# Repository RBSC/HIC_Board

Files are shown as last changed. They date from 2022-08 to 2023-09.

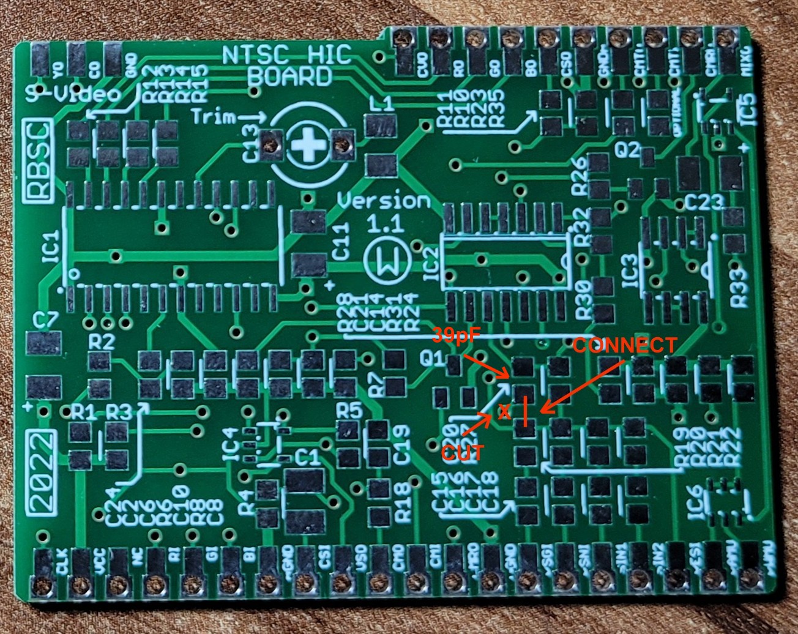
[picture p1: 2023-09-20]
Pics/v1_board_fix.jpg

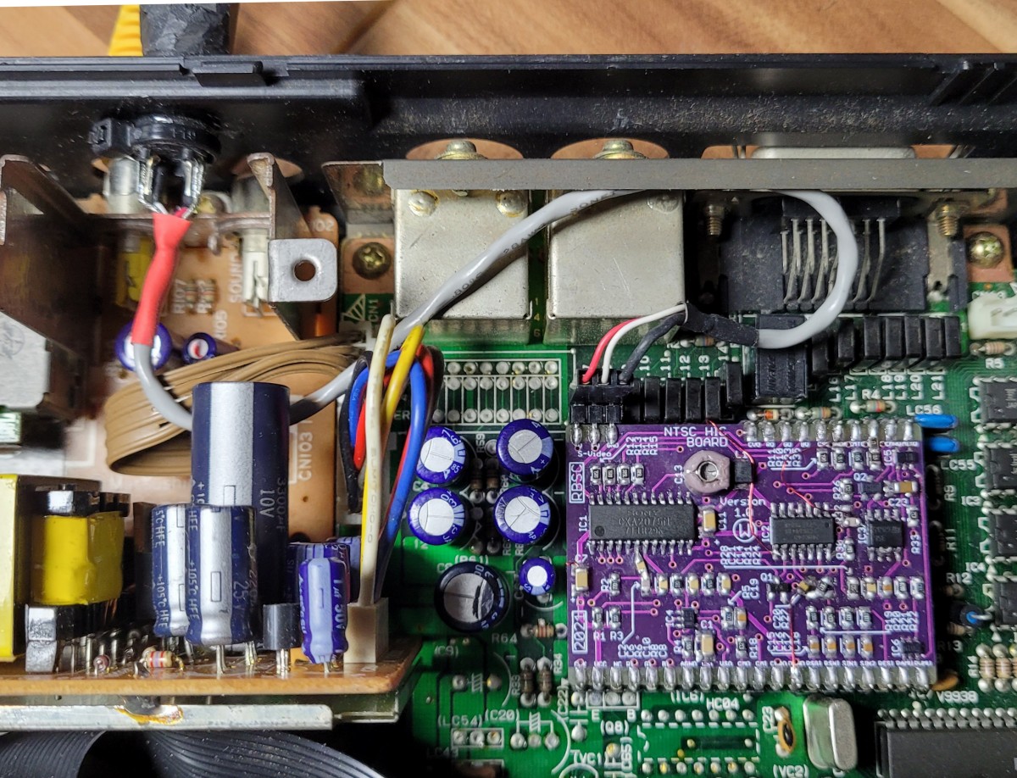
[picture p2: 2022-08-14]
Pics/installed.jpg

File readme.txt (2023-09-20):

--------------------------------------------------------------------------------
HIC Board version 1.2
Copyright (c) 2021-2023 RBSC
Last updated: 21.09.2023
--------------------------------------------------------------------------------

About
-----

It's a well-known fact that certain MSX2/2+ computers have a so-called "HIC Board" - the special "Hybrid IC" daughterboard that is
mounted onto the MSX computer's motherboard and provides certain functionality. This functionality is as follows:

 - converts RGBS signals to composite video
 - pre-amplifies and buffers audio
 - mutes audio at startup and on pause to prevent clicks
 - mixes all audio inputs
 - amplifies and buffers the cassette interface signals
 - buffers cassette interface's relay operations

This board is known to be installed in the following MSX computers:

 - Sony HB-F1II
 - Sony HB-F1XD
 - Sony HB-F1XV
 - Sony HB-F1XDJ
 - Sony HB-F1XDmkII
 - Panasonic FS-A1mkII
 - Panasonic FS-A1F
 - Kawai KMC-5000 (Panasonic FS-A1F OEM)

Normally, the board works just fine, but there's a problem with 3 electrolytic capacitors - they leak and damage the board,
sometimes beyond repair. Fixing the leaked boards is difficult as some components can separate from the corroded solder pads,
some tracks can be corroded under the CXA chip resulting in the board's malfunction.

The original HIC board's schematics and layout can be found here:
http://elec-junker-p2.blog.jp/MITSUMI%20EMC-NX0039_REV02_PU.pdf

HIC Board's Redesign
--------------------

Taking into account all the above listed problems, it was decided to clone the HIC board and at the same time add the following
improvements:

 - use a better and commonly available encoder chip CXA2075
 - add s-video output capability
 - try to get rid of the original 4069UBF chip's dependency
 - make the HIC board detachable

It was also desired to get rid of the 2 special components: IMN10 and FMW1, but they appeared to be still available for purchasing,
so they remained on the redesigned board.

During the redesign there appeared a few problems. The 4069UBF chip from Toshiba was used by the original engineers as an amplifier,
so the board's audio and cassette interface operations were dependent on certain features of that chip. When trying to replace this
chip with similar ones, for example 74LS04 or 74HCT04, the audio functionality was crippled. The only possible replacement appears
to be 74HC04 with 68pF capacitor added between pins 3 and 7 (GND). See the "74hc04_fix.jpg" image in the Pics folder.

The optional resistor R35 should not be installed unless the cassette input circuit doesn't work as desired.

Please note that R39 should be 0 Ohm resistor for all computers except for HB-F1XDJ. On that particular computer R39 should
be 220k.

Where to buy parts
------------------

At the time of this readme's creation the parts are available from the following sellers:

 - pin headers (male and female): https://www.aliexpress.com/item/4001122376295.html
 - CXA2075 encoder: https://www.aliexpress.com/item/33020885081.html
 - 4069UBF: https://www.aliexpress.com/item/1005002494421415.html
 - 68uH inductor: https://www.aliexpress.com/item/1005002963165525.html
 - LMV358M amplifier: https://www.aliexpress.com/item/4001116443945.html
 - 68pF trim capacitor: https://www.aliexpress.com/item/4000222152928.html
 - 2SA1037 transistor: https://www.aliexpress.com/item/1005002503421569.html
 - 2SC2411 transistor: https://www.aliexpress.com/item/1005004568437670.html
 - IMN10: https://www.aliexpress.com/item/1005004322498640.html
 - FMW1: https://www.ebay.com/itm/325038640119 or from Wierzbowsky (RBSC)

The resistors and capacitors 0805 and 1210 form factor can be ordered from any reasonable seller. The boards can be ordered from the
JLCPCB.COM factory.

IMPORTANT!
----------

The board hasn't been tested on all available MSX2/MSX2+ computers that are listed above. So far, the board was proved to be working
well on Panasonic A1 series computers, as well as on Sony F1-XV. There's still no feedback from some people who bought the HIC board
kits for other computers. As a result, the project's status is still WIP (work in progress).

The boards version 1.0 and 1.1 have an error that results in problems with PSG and FM sound on Sony HB-F1XDJ. The information on how
to fix the problem with those boards can be found in the "v1_board_fix.jpg" image file. One trace needs to be cut, 2 pads need to be
connected and C20 needs to be replaced with 39pF capacitor.

The RBSC provides all the files and information for free, without any liability (see the disclaimer.txt file). The provided information,
software or hardware must not be used for commercial purposes unless permitted by the RBSC. Producing a small amount of bare boards for
personal projects and selling the rest of the batch is allowed without the permission of RBSC.

When the sources of the tools are used to create alternative projects, please always mention the original source and the copyright!

Contact information
-------------------

The members of RBSC group Tnt23, Wierzbowsky, Pyhesty, Ptero, GreyWolf, SuperMax, VWarlock and DJS3000 can be contacted via the group's
e-mail address:

info@rbsc.su

The group's coordinator could be reached via this e-mail address:

admin@rbsc.su

The group's website can be found here:

https://rbsc.su/
https://rbsc.su/ru

The RBSC's hardware repository can be found here:

https://github.com/rbsc

The RBSC's 3D model repository can be found here:

https://www.thingiverse.com/groups/rbsc/things

-= ! MSX FOREVER ! =-

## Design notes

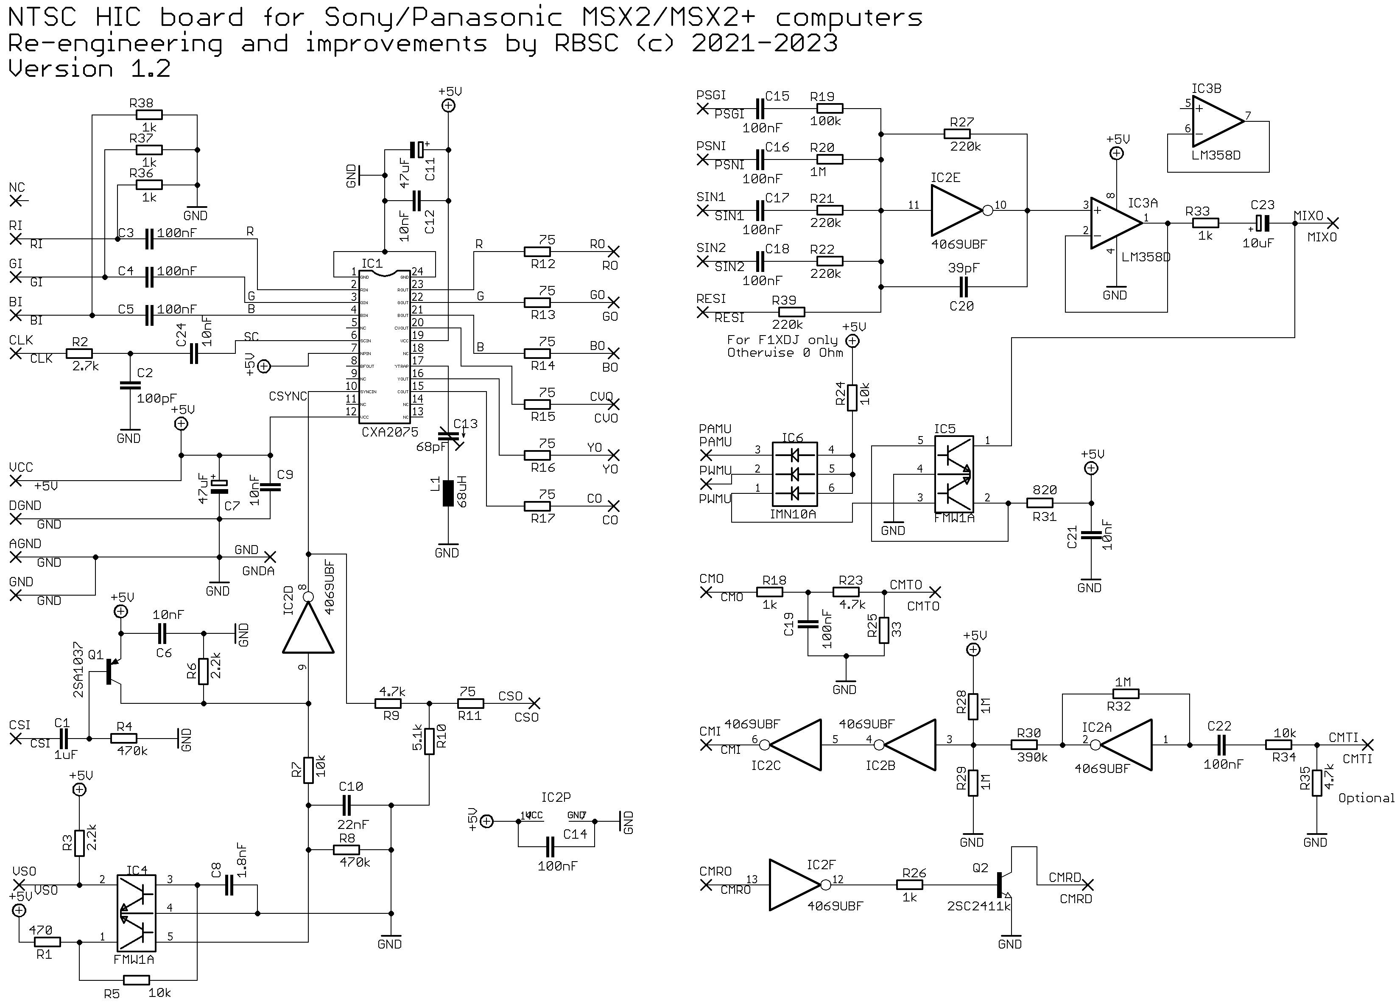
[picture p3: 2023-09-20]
Docs/schematics.png

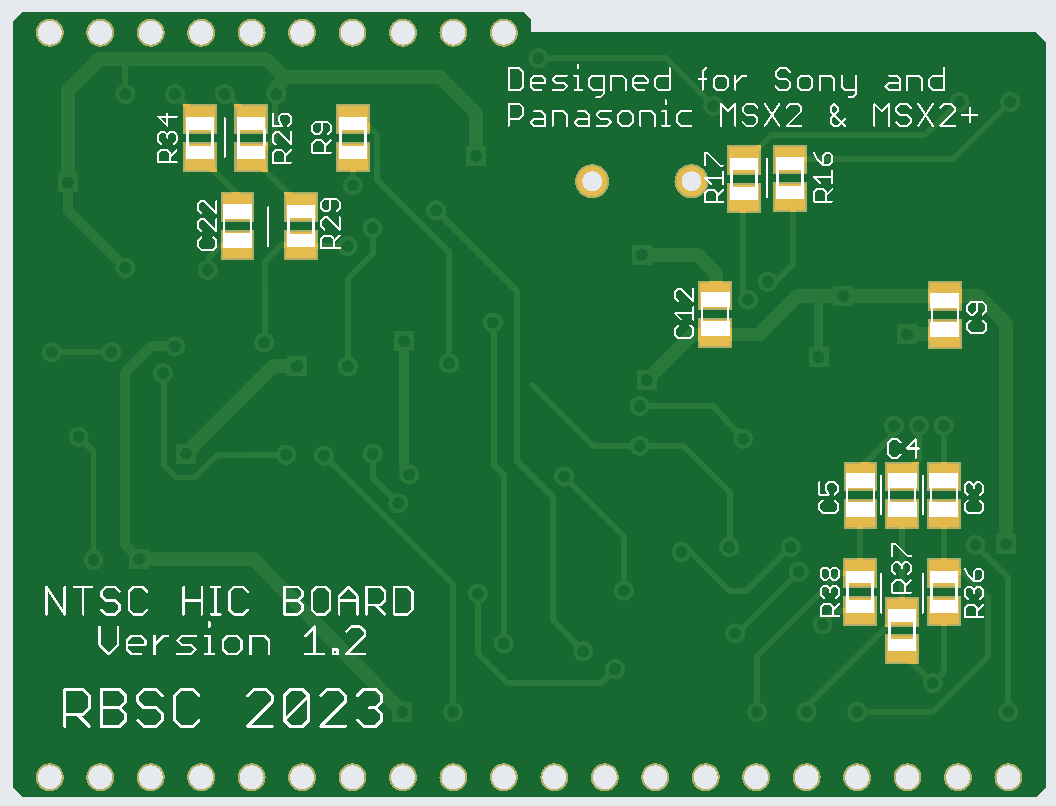
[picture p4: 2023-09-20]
Pics/board_bottom.png

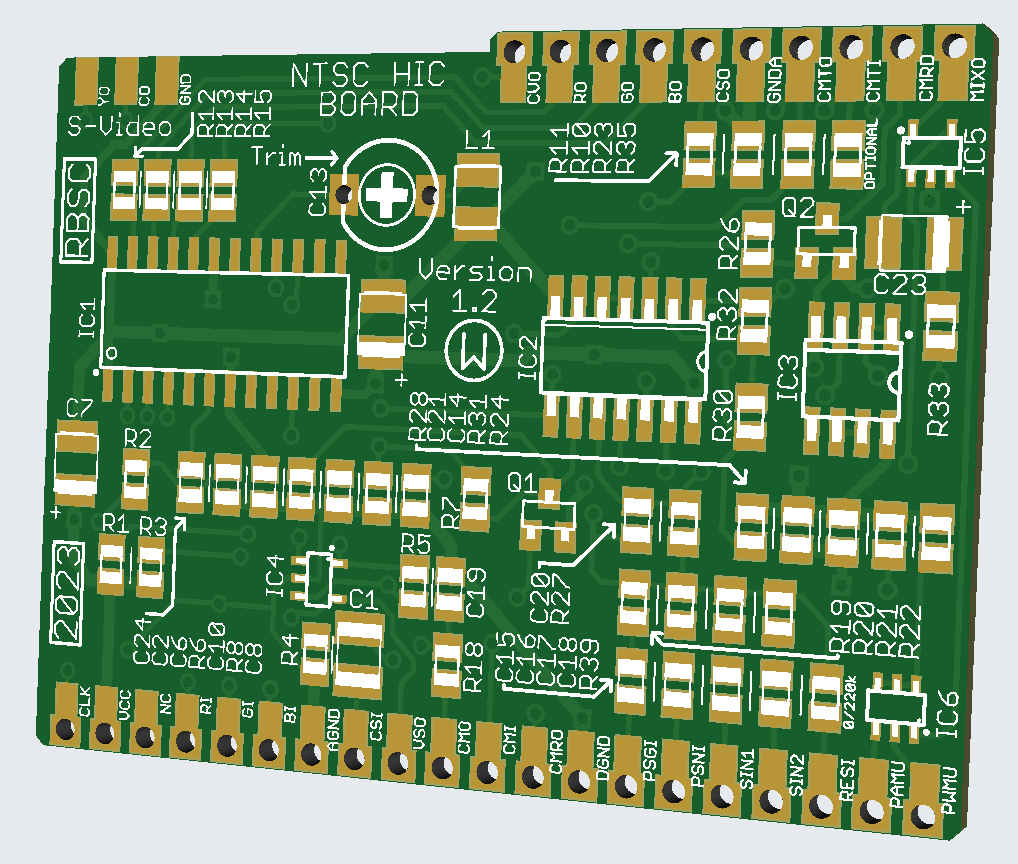
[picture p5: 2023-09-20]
Pics/board_3d.png

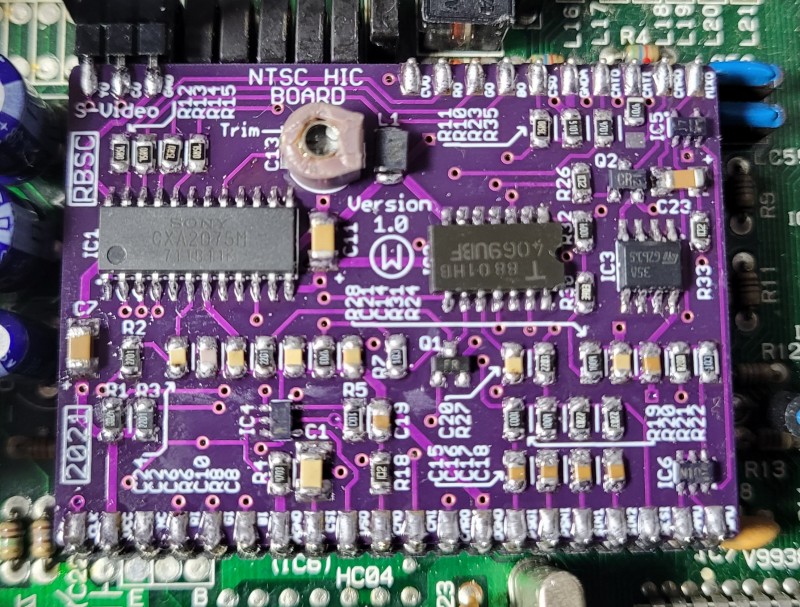
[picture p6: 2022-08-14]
Pics/board_v10.jpg

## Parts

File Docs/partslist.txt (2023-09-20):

Partlist
--------

Part     Value          Device               Package      Library         Sheet

C1       1uF            C-EUC1210            C1210        rcl             1
C2       100pF          C-EUC0805            C0805        rcl             1
C3       100nF          C-EUC0805            C0805        rcl             1
C4       100nF          C-EUC0805            C0805        rcl             1
C5       100nF          C-EUC0805            C0805        rcl             1
C6       10nF           C-EUC0805            C0805        rcl             1
C7       47uF           CPOL-EUSMCB          SMC_B        rcl             1
C8       1.8nF          C-EUC0805            C0805        rcl             1
C9       10nF           C-EUC0805            C0805        rcl             1
C10      22nF           C-EUC0805            C0805        rcl             1
C11      47uF           CPOL-EUSMCB          SMC_B        rcl             1
C12      10nF           C-EUC0805            C0805        rcl             1
C13      68pF           C-TRIMMTZ03          CTRIMTZ03    rcl             1
C14      100nF          C-EUC0805            C0805        rcl             1
C15      100nF          C-EUC0805            C0805        rcl             1
C16      100nF          C-EUC0805            C0805        rcl             1
C17      100nF          C-EUC0805            C0805        rcl             1
C18      100nF          C-EUC0805            C0805        rcl             1
C19      100nF          C-EUC0805            C0805        rcl             1
C20      39pF           C-EUC0805            C0805        rcl             1
C21      10nF           C-EUC0805            C0805        rcl             1
C22      100nF          C-EUC0805            C0805        rcl             1
C23      10uF           CPOL-EUSMCB          SMC_B        rcl             1
C24      10nF           C-EUC0805            C0805        rcl             1
IC1      CXA2075        CXA2075              SOP24        CXA2075M        1
IC2      4069UBF        74HCT04D             SO14         74xx-eu         1
IC3      LM358D         LM358D               SO08         linear          1
IC4      FMW1A          FMW1A                SMT5         fmw1            1
IC5      FMW1A          FMW1A                SMT5         fmw1            1
IC6      IMN10A         IMN10A               SMT6         imn10           1
L1       68uH           LL3225M              L3225M       eagle-ltspice   1
Q1       2SA1037        BCX71SMD             SOT23        transistor-pnp  1
Q2       2SC2411k       NPN-TRANSISTOR_SOT23 SOT23        semicon-smd-ipc 1
R1       470            R-EU_R0805           R0805        rcl             1
R2       2.7k           R-EU_R0805           R0805        rcl             1
R3       2.2k           R-EU_R0805           R0805        rcl             1
R4       470k           R-EU_R0805           R0805        rcl             1
R5       10k            R-EU_R0805           R0805        rcl             1
R6       2.2k           R-EU_R0805           R0805        rcl             1
R7       10k            R-EU_R0805           R0805        rcl             1
R8       470k           R-EU_R0805           R0805        rcl             1
R9       4.7k           R-EU_R0805           R0805        rcl             1
R10      5.1k           R-EU_R0805           R0805        rcl             1
R11      75             R-EU_R0805           R0805        rcl             1
R12      75             R-EU_R0805           R0805        rcl             1
R13      75             R-EU_R0805           R0805        rcl             1
R14      75             R-EU_R0805           R0805        rcl             1
R15      75             R-EU_R0805           R0805        rcl             1
R16      75             R-EU_R0805           R0805        rcl             1
R17      75             R-EU_R0805           R0805        rcl             1
R18      1k             R-EU_R0805           R0805        rcl             1
R19      100k           R-EU_R0805           R0805        rcl             1
R20      1M             R-EU_R0805           R0805        rcl             1
R21      220k           R-EU_R0805           R0805        rcl             1
R22      220k           R-EU_R0805           R0805        rcl             1
R23      4.7k           R-EU_R0805           R0805        rcl             1
R24      10k            R-EU_R0805           R0805        rcl             1
R25      33             R-EU_R0805           R0805        rcl             1
R26      1k             R-EU_R0805           R0805        rcl             1
R27      220k           R-EU_R0805           R0805        rcl             1
R28      1M             R-EU_R0805           R0805        rcl             1
R29      1M             R-EU_R0805           R0805        rcl             1
R30      390k           R-EU_R0805           R0805        rcl             1
R31      820            R-EU_R0805           R0805        rcl             1
R32      1M             R-EU_R0805           R0805        rcl             1
R33      1k             R-EU_R0805           R0805        rcl             1
R34      10k            R-EU_R0805           R0805        rcl             1
R35      4.7k           R-EU_R0805           R0805        rcl             1
R36      1k             R-EU_R0805           R0805        rcl             1
R37      1k             R-EU_R0805           R0805        rcl             1
R38      1k             R-EU_R0805           R0805        rcl             1
R39      0 Ohm/220k     R-EU_R0805           R0805        rcl             1

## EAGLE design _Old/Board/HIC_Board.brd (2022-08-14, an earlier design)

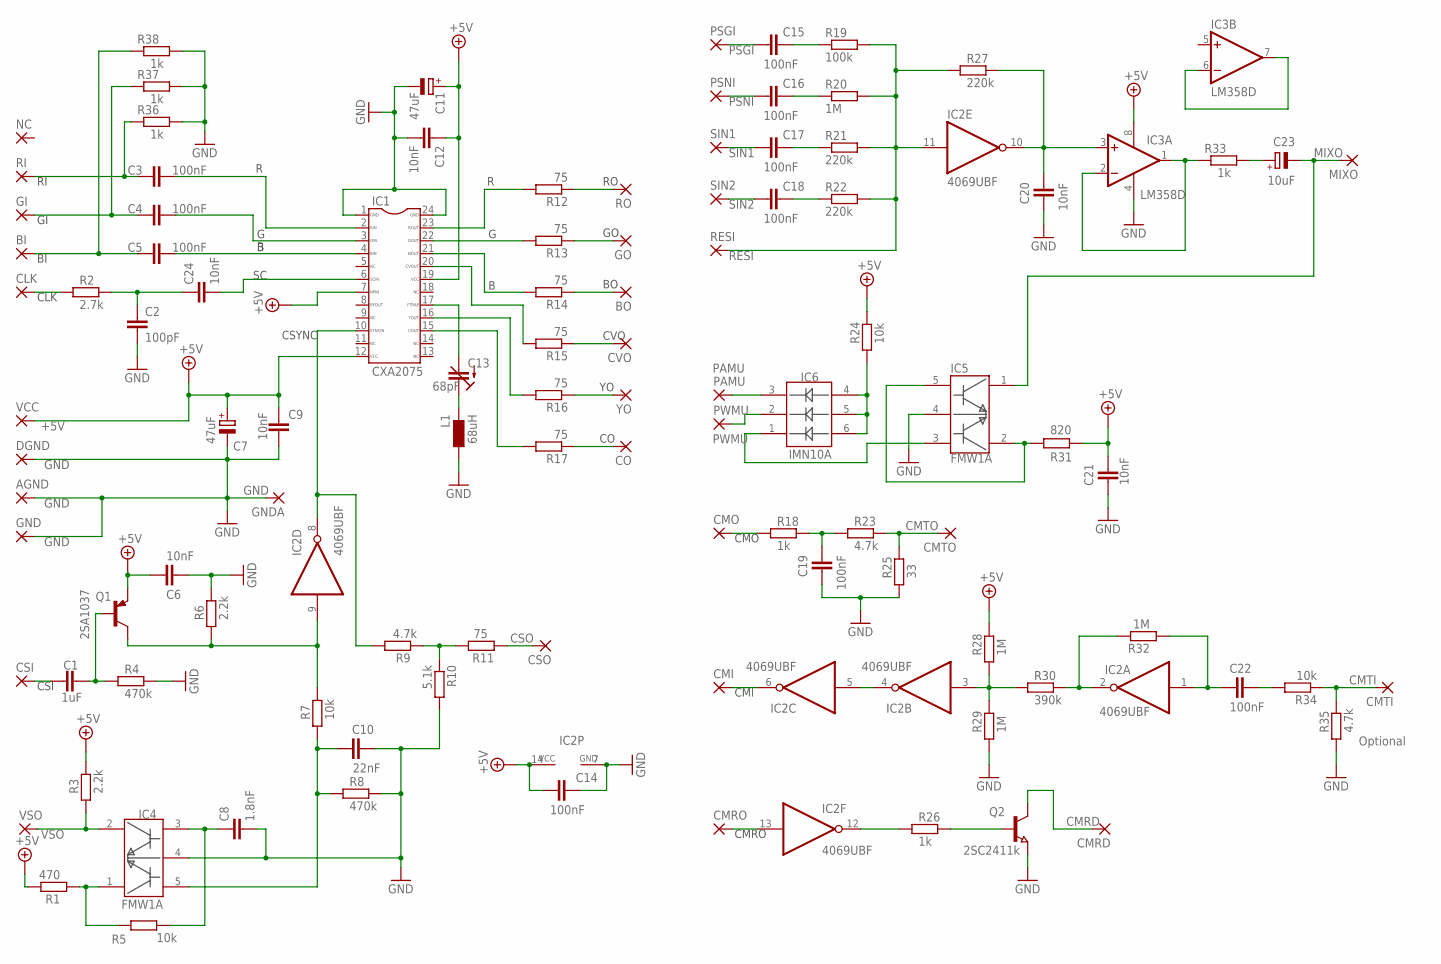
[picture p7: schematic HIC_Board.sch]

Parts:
AGND: HICPADSMD; SMD1,27-2,54
BI: HICPADSMD; SMD1,27-2,54
BO: HICPADSMD; SMD1,27-2,54
C1: 1uF; C1210
C2: 100pF; C0805
C3, C4, C5, C14, C15, C16, C17, C18, C19, C22: 100nF; C0805
C6, C9, C12, C20, C21, C24: 10nF; C0805
C7, C11: 47uF; SMC_B
C8: 1.8nF; C0805
C10: 22nF; C0805
C13: 68pF; CTRIMTZ03
C23: 10uF; SMC_B
CLK: HICPADSMD; SMD1,27-2,54
CMI: HICPADSMD; SMD1,27-2,54
CMO: HICPADSMD; SMD1,27-2,54
CMRD: HICPADSMD; SMD1,27-2,54
CMRO: HICPADSMD; SMD1,27-2,54
CMTI: HICPADSMD; SMD1,27-2,54
CMTO: HICPADSMD; SMD1,27-2,54
CO: HICPADSMD; SMD1,27-2,54
CSI: HICPADSMD; SMD1,27-2,54
CSO: HICPADSMD; SMD1,27-2,54
CVO: HICPADSMD; SMD1,27-2,54
DGND: HICPADSMD; SMD1,27-2,54
GI: HICPADSMD; SMD1,27-2,54
GND: HICPADSMD; SMD1,27-2,54
GNDA: HICPADSMD; SMD1,27-2,54
GO: HICPADSMD; SMD1,27-2,54
IC1: CXA2075; SOP24
IC2: 4069UBF; SO14
IC3: LM358D; SO08
IC4, IC5: FMW1A; SMT5
IC6: IMN10A; SMT6
L1: 68uH; L3225M
MIXO: HICPADSMD; SMD1,27-2,54
NC: HICPADSMD; SMD1,27-2,54
PAMU: HICPADSMD; SMD1,27-2,54
PSGI: HICPADSMD; SMD1,27-2,54
PSNI: HICPADSMD; SMD1,27-2,54
PWMU: HICPADSMD; SMD1,27-2,54
Q1: 2SA1037; SOT23
Q2: 2SC2411k; SOT23
R1: 470; R0805
R2: 2.7k; R0805
R3, R6: 2.2k; R0805
R4, R8: 470k; R0805
R5, R7, R24, R34: 10k; R0805
R9, R23, R35: 4.7k; R0805
R10: 5.1k; R0805
R11, R12, R13, R14, R15, R16, R17: 75; R0805
R18, R26, R33, R36, R37, R38: 1k; R0805
R19: 100k; R0805
R20, R28, R29, R32: 1M; R0805
R21, R22, R27: 220k; R0805
R25: 33; R0805
R30: 390k; R0805
R31: 820; R0805
RESI: HICPADSMD; SMD1,27-2,54
RI: HICPADSMD; SMD1,27-2,54
RO: HICPADSMD; SMD1,27-2,54
SIN1, SIN2: HICPADSMD; SMD1,27-2,54
VCC: HICPADSMD; SMD1,27-2,54
VSO: HICPADSMD; SMD1,27-2,54
YO: HICPADSMD; SMD1,27-2,54

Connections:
+5V: C6.1, C7.+, C9.2, C11.+, C12.1, C14.2, C21.2, IC1.7, IC1.12, IC1.19, IC2.14 (VCC), IC3.8 (V+), Q1.2 (E), R1.2, R3.2, R24.2, R28.2, R31.2, VCC.1
CMRD: CMRD.1, Q2.3 (C)
CMTI: CMTI.1, R34.1, R35.2
CMTO: CMTO.1, R23.2, R25.2
CSO: CSO.1, R11.1
GND: AGND.1, C2.1, C6.2, C7.-, C8.1, C9.1, C10.2, C11.-, C12.2, C14.1, C19.2, C20.2, C21.1, DGND.1, GND.1, GNDA.1, IC1.1, IC1.24, IC2.7 (GND), IC3.4 (V-), IC4.4, IC5.4, L1.1, Q2.2 (E), R4.2, R6.2, R8.2, R10.2, R25.1, R29.1, R35.1, R36.2, R37.2, R38.2
MIXO: C23.-, IC5.1, MIXO.1
unnamed: IC1.23, R12.2
unnamed: IC1.22, R13.2
unnamed: IC1.21, R14.2
unnamed: R12.1, RO.1
unnamed: GO.1, R13.1
unnamed: C3.1, R36.1, RI.1
unnamed: C4.1, GI.1, R37.1
unnamed: BO.1, R14.1
unnamed: R16.1, YO.1
unnamed: CVO.1, R15.1
unnamed: C2.2, C24.2, R2.2
unnamed: C1.2, CSI.1
unnamed: CLK.1, R2.1
unnamed: C13.1 (E), L1.2
unnamed: IC1.16, R16.2
unnamed: CMO.1, R18.1
unnamed: CMI.1, IC2.6 (O)
unnamed: C19.1, R18.2, R23.1
unnamed: IC2.4 (O), IC2.5 (I)
unnamed: C13.2 (A), IC1.17
unnamed: IC2.3 (I), R28.1, R29.2, R30.1
unnamed: CMRO.1, IC2.13 (I)
unnamed: IC2.2 (O), R30.2, R32.2
unnamed: C22.1, IC2.1 (I), R32.1
unnamed: C22.2, R34.2
unnamed: IC2.12 (O), R26.1
unnamed: Q2.1 (B), R26.2
unnamed: C17.2, R21.1
unnamed: C15.2, R19.1
unnamed: C16.2, R20.1
unnamed: C18.2, R22.1
unnamed: C20.1, IC2.10 (O), IC3.3 (+IN), R27.2
unnamed: C23.+, R33.2
unnamed: IC3.6 (-IN), IC3.7 (OUT)
unnamed: IC5.2, IC5.5, R31.1
unnamed: IC5.3, IC6.1
unnamed: IC6.4, IC6.5, IC6.6, R24.1
unnamed: C1.1, Q1.1 (B), R4.1
unnamed: IC3.1 (OUT), IC3.2 (-IN), R33.1
unnamed: IC2.9 (I), Q1.3 (C), R6.1, R7.2
unnamed: C8.2, IC4.3, R5.2
unnamed: BI.1, C5.1, R38.1
unnamed: C4.2, IC1.3
unnamed: C3.2, IC1.2
unnamed: C5.2, IC1.4
unnamed: IC1.10, IC2.8 (O), R9.2
unnamed: IC4.1, R1.1, R5.1
unnamed: R9.1, R10.1, R11.2
unnamed: C10.1, IC4.5, R7.1, R8.1
unnamed: C24.1, IC1.6
unnamed: IC1.20, R15.2
unnamed: CO.1, R17.1
unnamed: IC1.15, R17.2
PAMU: IC6.3, PAMU.1
PSGI: C15.1, PSGI.1
PSNI: C16.1, PSNI.1
PWMU: IC6.2, PWMU.1
RESI: IC2.11 (I), R19.2, R20.2, R21.2, R22.2, R27.1, RESI.1
SIN1: C17.1, SIN1.1
SIN2: C18.1, SIN2.1
VSO: IC4.2, R3.1, VSO.1

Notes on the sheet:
CSYNC
CVO
CLK
CMO
CMI
CMRO
CSI
Optional

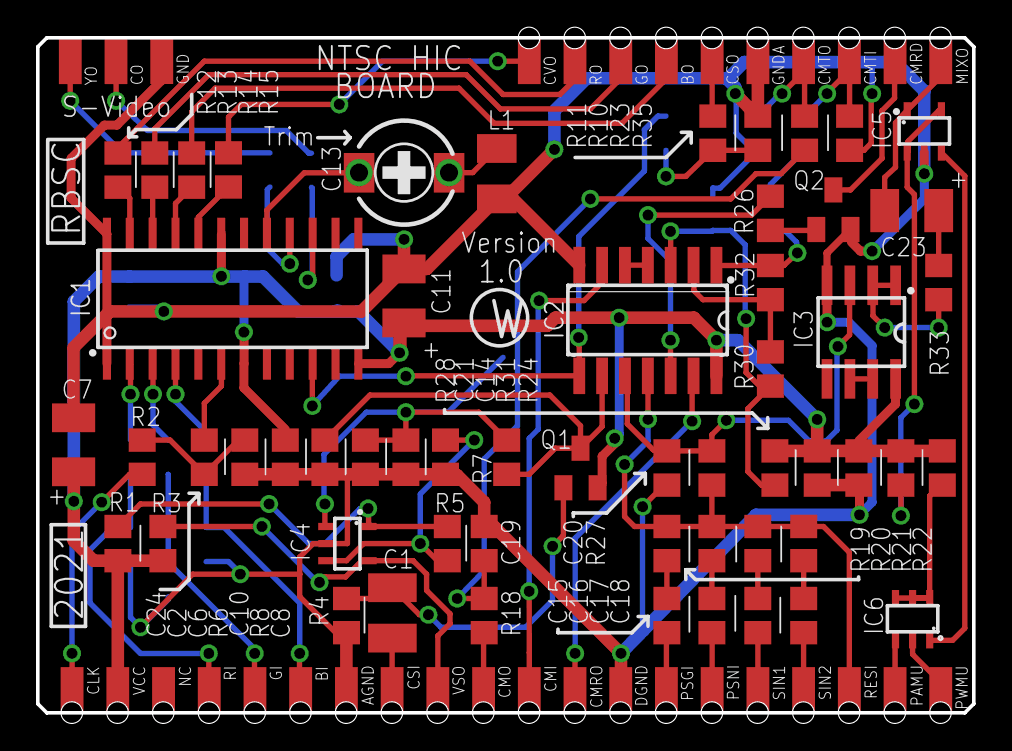
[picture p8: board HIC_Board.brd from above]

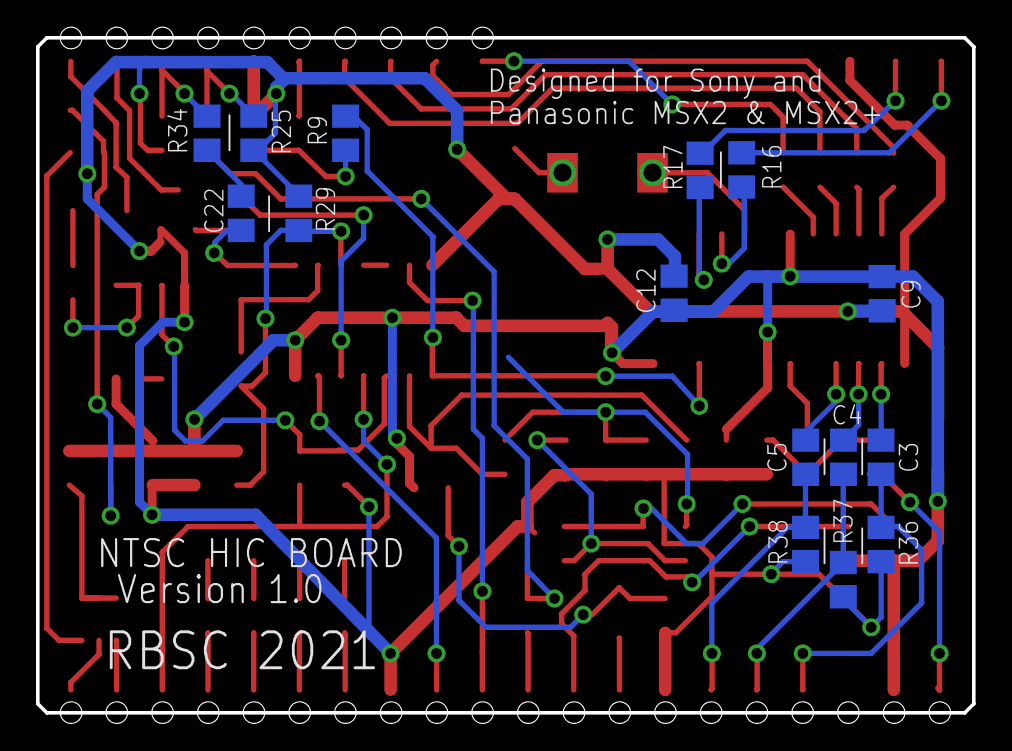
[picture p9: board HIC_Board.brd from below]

Board: 2 copper layers, 52.0 x 37.5 mm, 104 parts (15 on the bottom side), 68 nets.

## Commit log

2022-08-14 Initial release 14.08.2022
    Initial release of the board v1.0
    [HIC_Board.GBL, HIC_Board.GBO, HIC_Board.GBP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]
2022-08-14 Initial release 14.08.2022
    Initial release of the v1.0 board
2023-09-20 Updated 21.09.2023
    Updated to v1.2. The error was fixed, the resistor was added for HB-F1XDJ computer (see the readme file)
    [HIC_Board.GBL, HIC_Board.GBO, HIC_Board.GBP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]
2023-09-20 Added old release files
    Old release files v1.0
    [HIC_Board.GBL, HIC_Board.GBO, HIC_Board.GBP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]

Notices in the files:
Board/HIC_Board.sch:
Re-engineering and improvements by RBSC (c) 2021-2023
